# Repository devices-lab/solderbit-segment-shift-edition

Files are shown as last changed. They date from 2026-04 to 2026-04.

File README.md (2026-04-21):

# solder:bit Segment _Shift Edition_

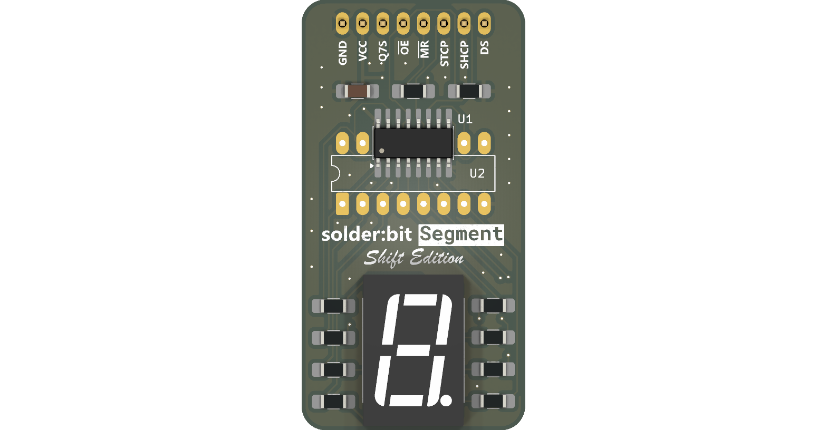
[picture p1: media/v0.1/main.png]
solder:bit Segment Shift Edition A render of the latest solder:bit Segment Shift Edition


The solder:bit Segment _Shift Edition_ is a variant of the original [solder:bit Segment](https://github.com/devices-lab/solderbit-segment), designed for learning to solder both surface-mount (SMT) and through-hole (THT) components. Once assembled, it can display a single digit on a 7-segment display, driven by an 8-bit serial-in parallel-out (SIPO) shift register.

This soldering kit is designed to accommodate a wide range of soldering abilities. The shift register is available in two different packages. The 74HC595D in the **SOP-16** package is smaller and more challenging to solder, while the SN74HC595N in the **DIP-16** package is larger and through-hole (THT), making it more accessible for novices. The same printed circuit board (PCB) has footprints for both packages, and you choose which component to solder based on your ability. The device functions identically regardless of which package you use. Note that once you have soldered one package, the footprint for the other will no longer be accessible.

| Shift register in an SOP-16 package (SMT) | Shift register in a DIP-16 package (THT) |
| --- | --- |
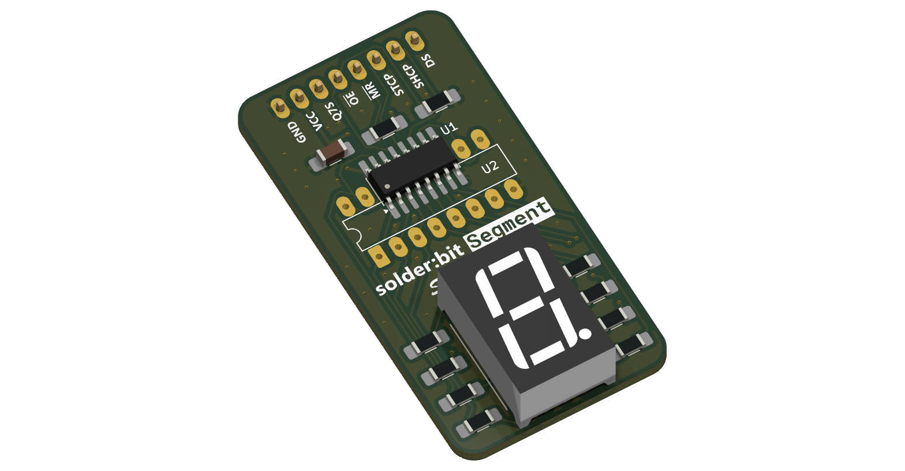
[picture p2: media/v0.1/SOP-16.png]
SMT
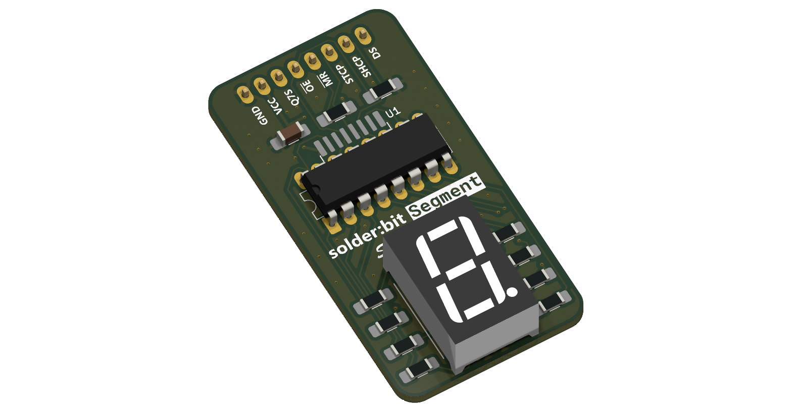
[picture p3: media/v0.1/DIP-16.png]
THT
|  |  |

## Getting started

> [!WARNING]
> This device is a research prototype and is provided as-is. Use it at your own risk. The authors take no responsibility for any damage, injury, or loss arising from its use.

To get started, you will need the following:

1. The printed circuit boards (PCBs), which you will need to have manufactured.
2. All components listed in the bill of materials (BOM).
3. A microcontroller development board, like the BBC micro:bit.
4. All equipment and materials required for soldering.

### Printed circuit boards (PCBs)

The solder:bit Segment _Shift Edition_ fabrication files are open source, so you can order the PCBs yourself!

To fabricate the PCB, use the files in the [gerbers-v0.1](/fabrication/gerbers-v0.1/) folder.

### Components

> [!NOTE]
> Most of these components are sourced from [Onecall (Farnell/CPC)](https://onecall.farnell.com/) and [LCSC](https://lcsc.com), but as they are fairly common components, alternatives can be found from other suppliers such as DigiKey and others.

| Reference | Quantity | Part | Package | Onecall order code | LCSC part number |
| --- | --- | --- | --- | --- | --- |
| C1 | 1 | 1 µF \* | 1206 | 3188966 | [C1848](https://www.lcsc.com/product-detail/C1848.html) |
| DS1 | 1 | SM420561N \* | Through Hole | 3648330 | [C141367](https://www.lcsc.com/product-detail/C141367.html) |
| J1 | 1 | 8-pin header \* | 2.54mm, THT  | 1593416 | [C492407](https://www.lcsc.com/product-detail/C492407.html) |
| R1, R2 | 2 | 100 kΩ \* | 1206 | 9241060 | [C17900](https://www.lcsc.com/product-detail/C17900.html) |
| R3–R10 | 8 | 300 Ω \* | 1206 | 9240420 | [C17887](https://www.lcsc.com/product-detail/C17887.html) |
| U1 | 1 | 74HC595D | SOP-16 | 1201269 | [C5144558](https://www.lcsc.com/product-detail/C5144558.html) |
| U2 | 1 | SN74HC595N | DIP-16 | 3120865 | [C507175](https://www.lcsc.com/product-detail/C507175.html) |

_\* Generic component; the order code is provided as a reference, but any equivalent component in the same package can be substituted._

Note that U1 and U2 are alternative packages for the same 74HC595 component — you only need one. You can source both and choose whichever you are more comfortable soldering.

The 7-segment display(s) listed above has red segments. If you would like other colours, note that you might need to adjust R3-R10 resistor values. Also note that you will need a larger resistor value (at least 350 Ω) if you are powering the device with 5 V instead of 3.3 V. This is to ensure the output current from all output pins on the shift register doesn't exceed 70 mA in total.

Depending on how you plan to connect the solder:bit Segment _Shift Edition_ to your microcontroller development board, you may also need a breadboard and some jumper cables.

### Development board

You can use a BBC micro:bit to control the solder:bit Segment _Shift Edition_. Once assembled, attach the device to a breadboard, plug the micro:bit into a [breadboard adaptor](https://kitronik.co.uk/products/5664-microbit-breadboard-breakout-board), and connect it to the breadboard. See the [programming](#programming) section below to see how to wire it up.

> [!CAUTION]
> The device operates at supply voltages (VDD) between 2.1 V and 6 V. When running at 5 V or higher, resistors R3-R10 must be at least 350 Ω to keep the current within safe limits.

The solder:bit Segment _Shift Edition_ can also be used with other microcontroller development boards such as the [Raspberry Pi Pico](https://www.raspberrypi.com/products/raspberry-pi-pico/) or [Arduino Uno](https://store.arduino.cc/products/arduino-uno-rev3), however we currently only provide programming support for the micro:bit.

See the [programming](#programming) section below for how to write code to control the solder:bit Segment _Shift Edition_.

### Equipment and materials for soldering

The required equipment will vary depending on your soldering setup and needs, but the following is what you will generally need:

- Safety goggles
- Fume extractor fan
- Soldering iron
- Soldering iron stand
- Brass wool
- Silicone mat
- Solder
- Tweezers
- Solder wick

The following items are optional but useful:

- Blue Tack (for keeping the PCB in place)
- PCB holder/helping hands
- Flux
- Tip cleaner
- Desoldering pump
- Isopropyl alcohol (IPA) and cotton swabs
- Multimeter (for checking continuity in solder joints)

> [!CAUTION]
> To minimise health hazards, we recommend using lead-free and rosin-free solder and flux.

> [!TIP]
> If you are running this as a workshop/event activity, an [HDMI digital microscope](https://www.amazon.co.uk/dp/B09VPPS96M) connected to a display is very useful for streaming a soldering demonstration to the entire room.

> [!TIP]
> Smaller soldering iron tips make it easier to reach tight spaces, but they transfer heat less effectively. We recommend trying out a few different tip sizes and choosing one that works well with your soldering iron.

## Assembly instructions

Coming soon...

## Programming

If you are using a BBC micro:bit, you can program the solder:bit Segment _Shift Edition_ in [MakeCode](https://makecode.microbit.org/) using the [pxt-solderbit-segment](https://github.com/devices-lab/pxt-solderbit-segment) extension.

You can test if your assembled device works by flashing the micro:bit with the [demo file](/demo/microbit-solderbit-segment-shift-edition-demo.hex). Attach the solder:bit Segment _Shift Edition_ to a breadboard, insert the micro:bit into a [breadboard adaptor](https://kitronik.co.uk/products/5664-microbit-breadboard-breakout-board), and plug it into the breadboard. Connect the device to the micro:bit using the following pinout:

| solder:bit Segment _Shift Edition_ | BBC micro:bit |
| --- | --- |
| GND | GND |
| VCC | 3V |
| STCP | P2 |
| SHCP | P1 |
| DS | P0 |

See [this image](/demo/wiring_front.jpeg) for an example of how to wire it up.

For any other development board, you will need to write the firmware yourself. Refer to the [solder:bit Segment Shift Edition schematic](/reference/solderbit%20Segment%20Shift%20Edition%20v0.1%20schematic.pdf), the datasheets for the I/O expanders (both packages), and the 7-segment display datasheet, all of which are available in the [reference](/reference/) folder.

> [!NOTE]
> The [pxt-solderbit-segment](https://github.com/devices-lab/pxt-solderbit-segment) MakeCode extension handles the original solder:bit Segment as well as this newer solder:bit Segment _Shift Edition_.

## Project status and contributing

This project is actively maintained. See [CHANGELOG.md](/CHANGELOG.md) for the latest changes.

At this time, external contributions are not being accepted. If you have suggestions or have found an issue, feel free to open a GitHub issue and we will take a look.

## Contact

If you are interested in using solder:bit kits for your classroom, university, conference, or any other workshop or event, feel free to reach out to me @mac-aron or contact [Devices Lab](https://devices-lab.org/contact).

## Acknowledgements

Special thanks to everyone at the [Devices Lab](https://www.devices-lab.org/) for their ongoing support on this project and for their help running soldering workshops.

## License

This project is licensed under the GNU General Public License (GPL), version 3. This license allows you to use, modify, and redistribute the solder:bit Segment _Shift Edition_ and any derivative works, but all such derivatives must also be licensed under the GPL.

The GPL ensures that all modifications and improvements to the solder:bit Segment _Shift Edition_ remain free and open for the public benefit. By using this project, you agree to abide by its terms and conditions.

For more details on the license, please see the [LICENSE](/LICENSE) file included in this repository.

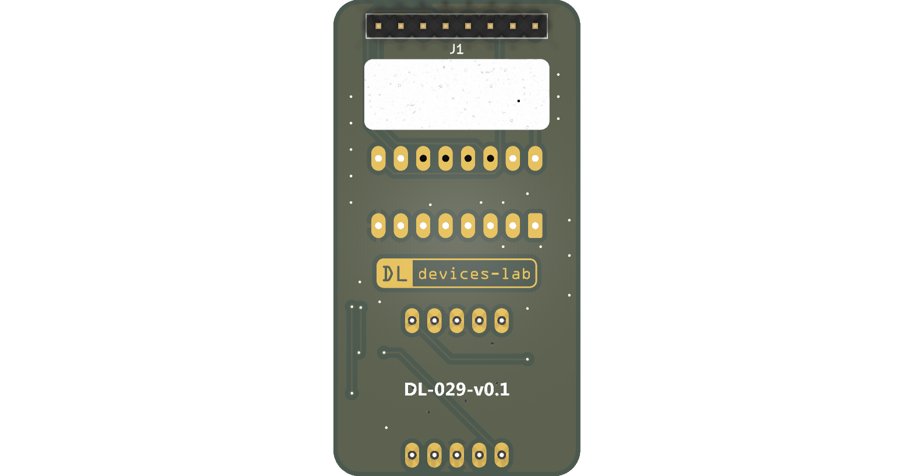
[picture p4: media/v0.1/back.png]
Back of the solder:bit Segment Shift Edition A render of the back of the latest solder:bit Segment Shift Edition


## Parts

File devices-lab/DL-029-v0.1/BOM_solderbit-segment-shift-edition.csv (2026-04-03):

Reference | Value | Package | LCSC Part
U1 | 74HC595D | SOP-16 | C5144558
R3,R4,R5,R6,R7,R8,R9,R10 | 300R | 1206 | C17887
R1,R2 | 100k | 1206 | C17900
DS1 | SM420561N | Through Hole | C141367
C1 | 1uF | 1206 | C1848

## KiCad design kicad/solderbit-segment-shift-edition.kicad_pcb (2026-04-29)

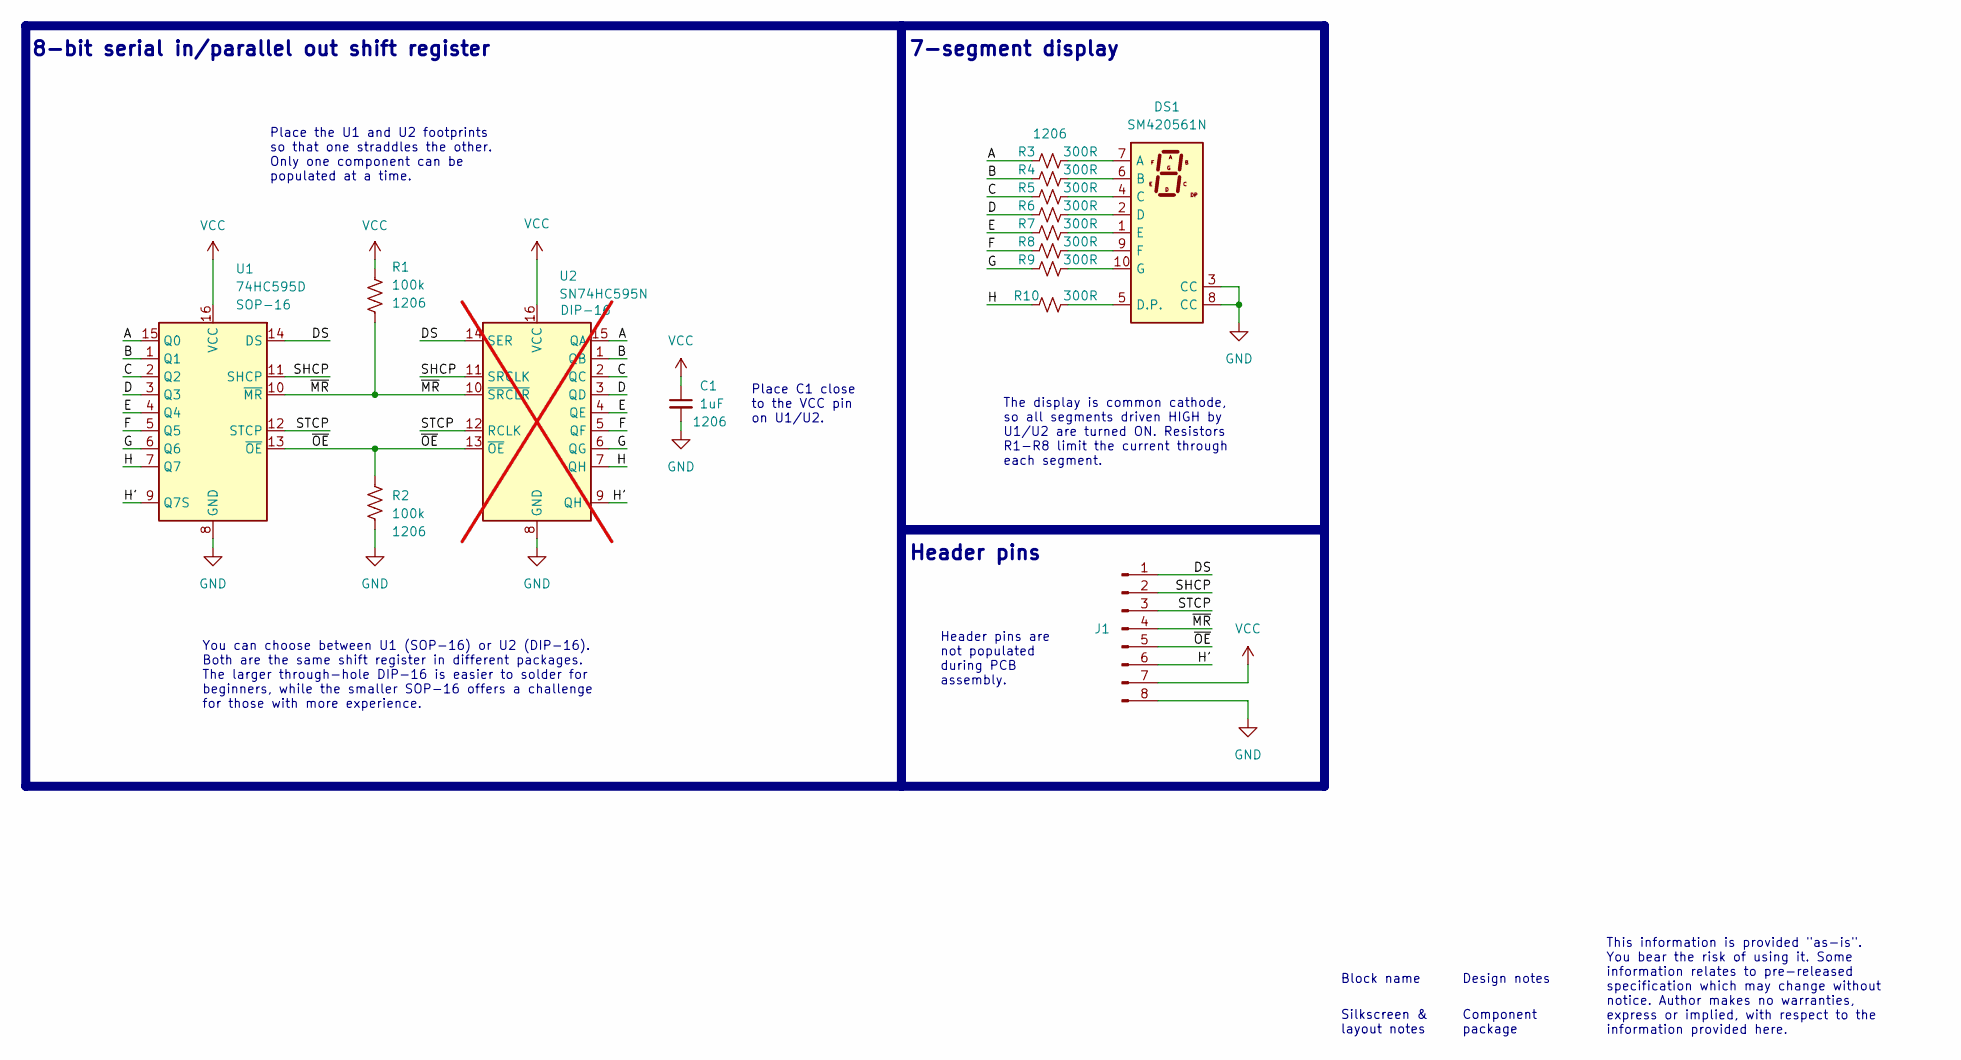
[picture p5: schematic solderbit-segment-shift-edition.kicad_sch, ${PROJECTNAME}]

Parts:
C1: 1uF; C_1206; LCSC Part C1848
DS1: SM420561N; DISPLAY_7SEGMENT_0.56__THT; LCSC Part C141367
J1: Conn_01x08_Pin; PinHeader_1x08_P2.54mm_Vertical; LCSC Part C492407
R1, R2: 100k; R_1206; LCSC Part C17900
R3, R4, R5, R6, R7, R8, R9, R10: 300R; R_1206; LCSC Part C17887
U1: 74HC595D; SOIC-16_3.9x9.9mm_P1.27mm; LCSC Part C5144558
U2: SN74HC595N; DIP-16_W7.62; LCSC Part C507175; not fitted

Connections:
/A: R3.1, U1.15 (Q0), U2.15 (QA)
/B: R4.1, U1.1 (Q1), U2.1 (QB)
/C: R5.1, U1.2 (Q2), U2.2 (QC)
/D: R6.1, U1.3 (Q3), U2.3 (QD)
/DS: J1.1, U1.14 (DS), U2.14 (SER)
/E: R7.1, U1.4 (Q4), U2.4 (QE)
/F: R8.1, U1.5 (Q5), U2.5 (QF)
/G: R9.1, U1.6 (Q6), U2.6 (QG)
/H: R10.1, U1.7 (Q7), U2.7 (QH)
/H': J1.6, U1.9 (Q7S), U2.9 (QH')
/SHCP: J1.2, U1.11 (SHCP), U2.11 (SRCLK)
/STCP: J1.3, U1.12 (STCP), U2.12 (RCLK)
/~MR: J1.4, R1.2, U1.10 (~MR), U2.10 (~SRCLR)
/~OE: J1.5, R2.1, U1.13 (~OE), U2.13 (~OE)
GND: C1.2, DS1.3 (CC), DS1.8 (CC), J1.8, R2.2, U1.8 (GND), U2.8 (GND)
unnamed: DS1.7 (A), R3.2
unnamed: DS1.6 (B), R4.2
unnamed: DS1.4 (C), R5.2
unnamed: DS1.2 (D), R6.2
unnamed: DS1.5 (D.P.), R10.2
unnamed: DS1.1 (E), R7.2
unnamed: DS1.9 (F), R8.2
unnamed: DS1.10 (G), R9.2
VCC: C1.1, J1.7, R1.1, U1.16 (VCC), U2.16 (VCC)

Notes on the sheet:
Silkscreen & layout notes
Component package
Place the U1 and U2 footprints so that one straddles the other. Only one component can be populated at a time.
Header pins are not populated during PCB assembly.
The display is common cathode, so all segments driven HIGH by U1/U2 are turned ON. Resistors R1-R8 limit the current through each segment.
You can choose between U1 (SOP-16) or U2 (DIP-16). Both are the same shift register in different packages. The larger through-hole DIP-16 is easier to solder for beginners, while the smaller SOP-16 offers a challenge for those with more experience.
Header pins
Block name
This information is provided "as-is". You bear the risk of using it. Some information relates to pre-released specification which may change without notice. Author makes no warranties, express or implied, with respect to the information provided here.
7-segment display
8-bit serial in/parallel out shift register
Place C1 close to the VCC pin on U1/U2.
Design notes

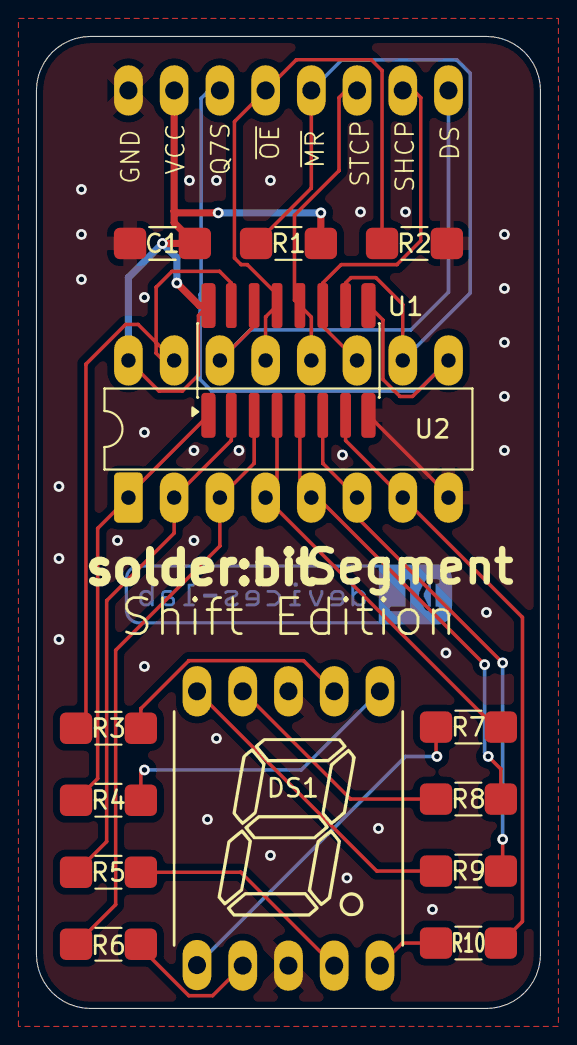
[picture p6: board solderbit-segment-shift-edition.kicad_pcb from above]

Board: 2 copper layers, 28.0 x 54.0 mm, 15 parts (1 on the bottom side), 24 nets.

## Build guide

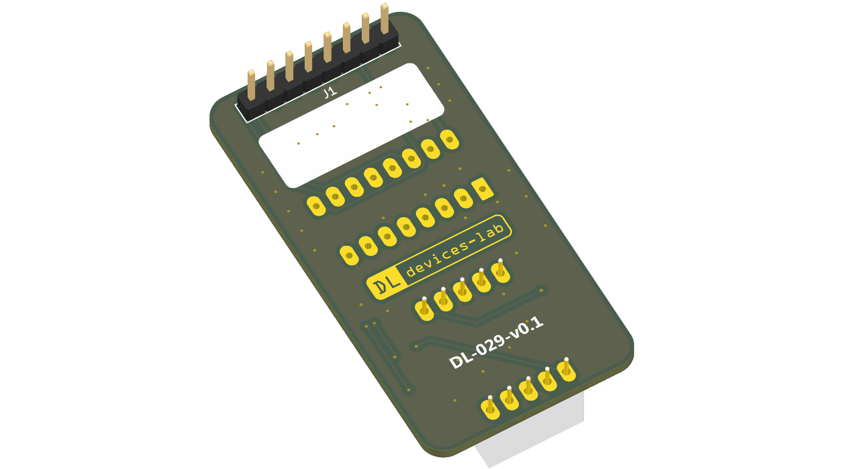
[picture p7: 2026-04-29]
assembly/step_06_SOP.png

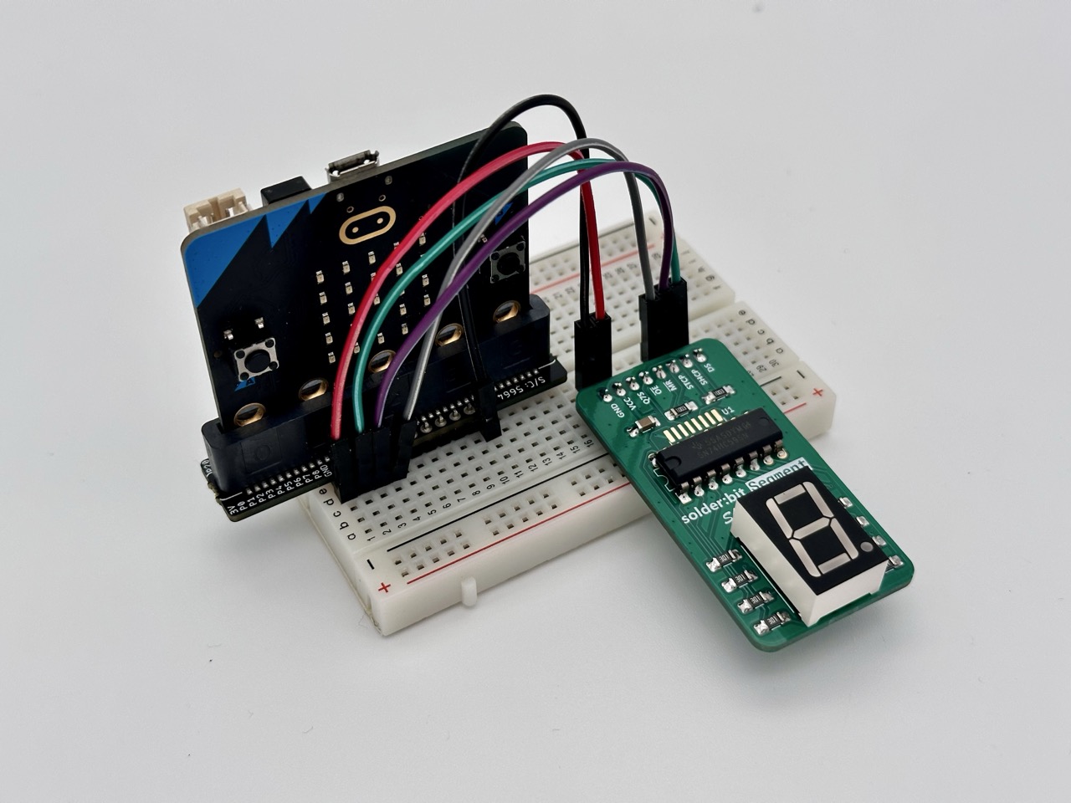
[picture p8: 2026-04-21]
demo/wiring_front.jpeg

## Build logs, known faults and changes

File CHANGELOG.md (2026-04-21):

# Changelog for solder:bit Segment Shift Edition

Each version captures specific changes categorized under "Added", "Changed", "Removed", and "Fixed" to provide an overview of the development progression.

## v0.1

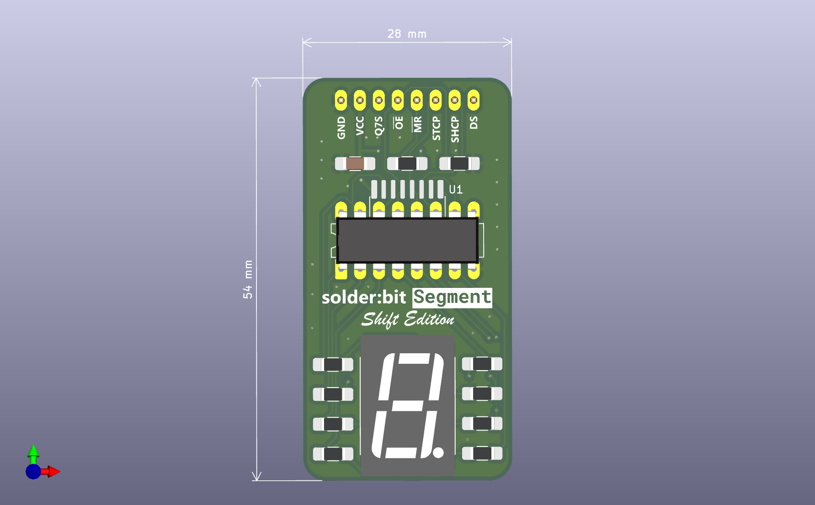
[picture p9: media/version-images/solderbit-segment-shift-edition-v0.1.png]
Device in version 0.1 solder:bit Segment Shift Edition v0.1


### Added

- First version of the PCB

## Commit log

2026-04-21 Update all documentation
    [CPL_solderbit-segment-shift-edition-top-pos.csv, solderbit-segment-shift-edition-B_Cu.gbl, solderbit-segment-shift-edition-B_Fab.gbr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]
2026-04-21 Gerber files
    [solderbit-segment-shift-edition-B_Cu.gbl, solderbit-segment-shift-edition-B_Fab.gbr, solderbit-segment-shift-edition-B_Mask.gbs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]
2026-04-22 Update device renders with green silkscreen
2026-04-22 KiCad 10 first save
    [solderbit-segment-shift-edition.kicad_pcb, solderbit-segment-shift-edition.kicad_sch]
2026-04-29 Assembly images
2026-04-29 Remove DNP flag for header pins
    [solderbit-segment-shift-edition.kicad_sch]
2026-04-29 Export an updated schematic
2026-04-29 Full assembly images
    [solderbit-segment-shift-edition.kicad_pcb]
